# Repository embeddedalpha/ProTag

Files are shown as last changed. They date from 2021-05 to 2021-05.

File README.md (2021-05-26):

# ProTag  

### Schematic:

### 1
ProTag_Back_Ortho

### 2
ProTag_Front

### 3
ProTag_Back

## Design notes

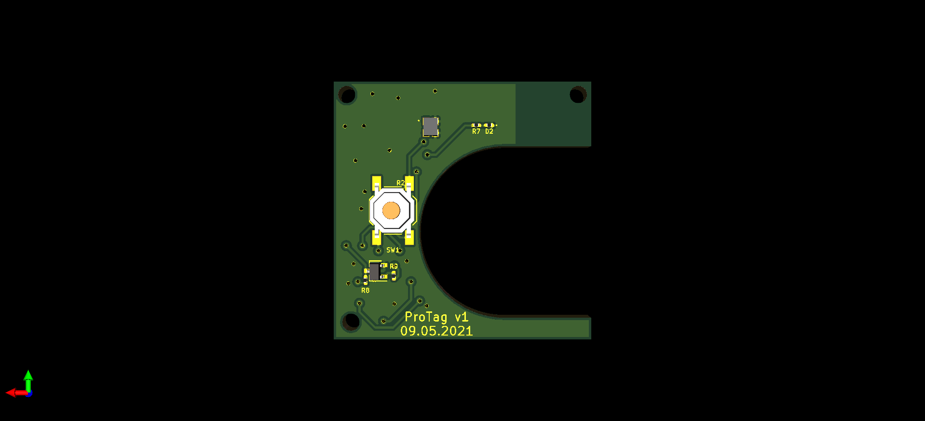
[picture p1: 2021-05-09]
Photos/ProTag_Back.png

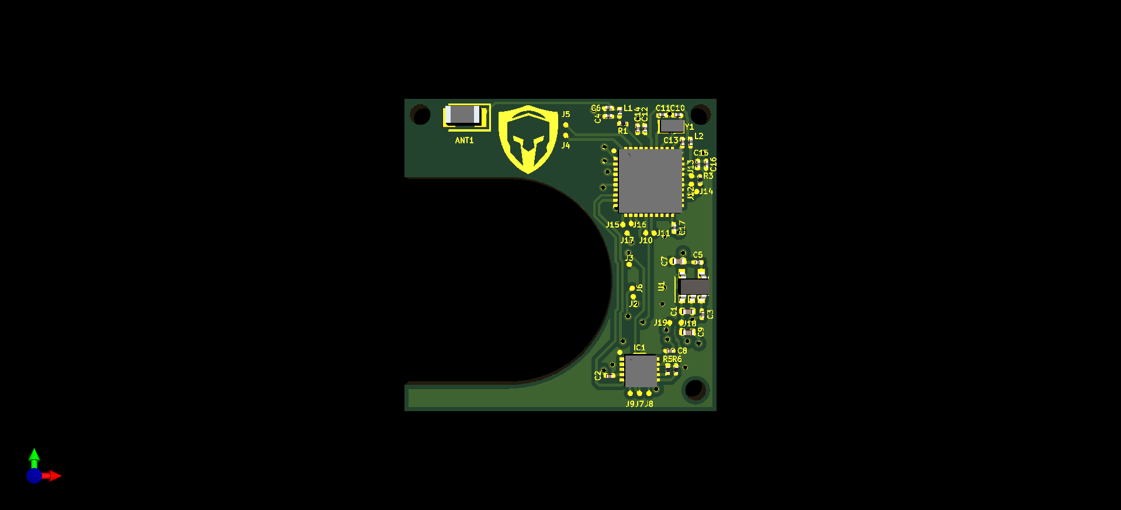
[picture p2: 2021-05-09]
Photos/ProTag_Front.png

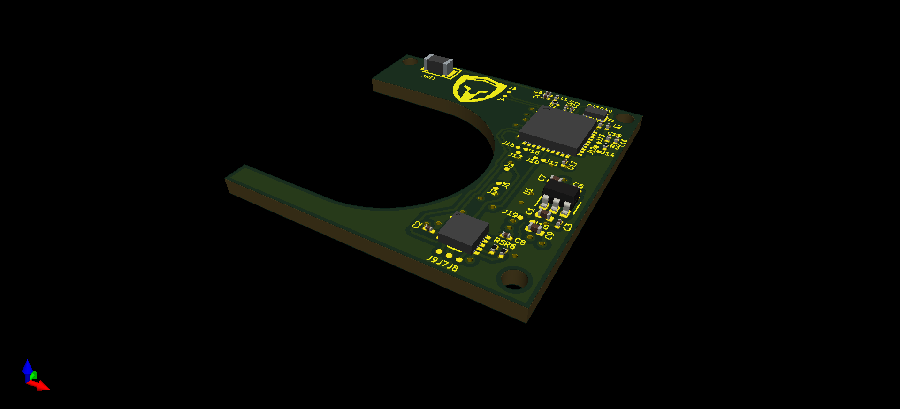
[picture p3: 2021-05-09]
Photos/ProTag_Back_Ortho.png

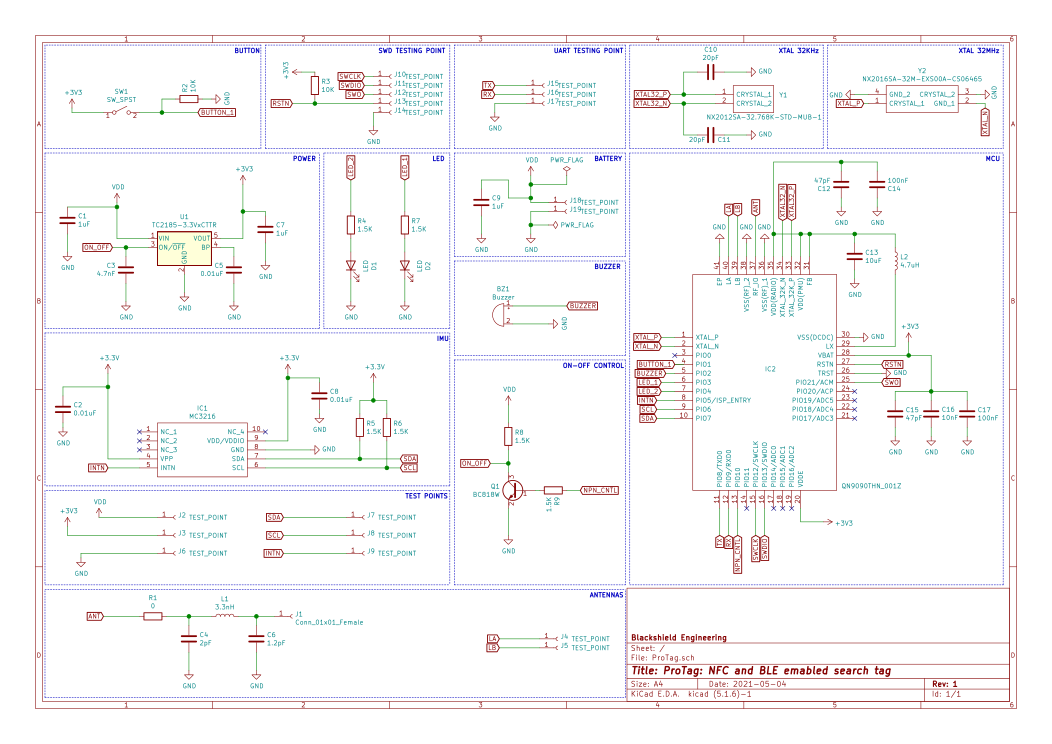
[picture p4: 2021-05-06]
Photos/ProTag.png

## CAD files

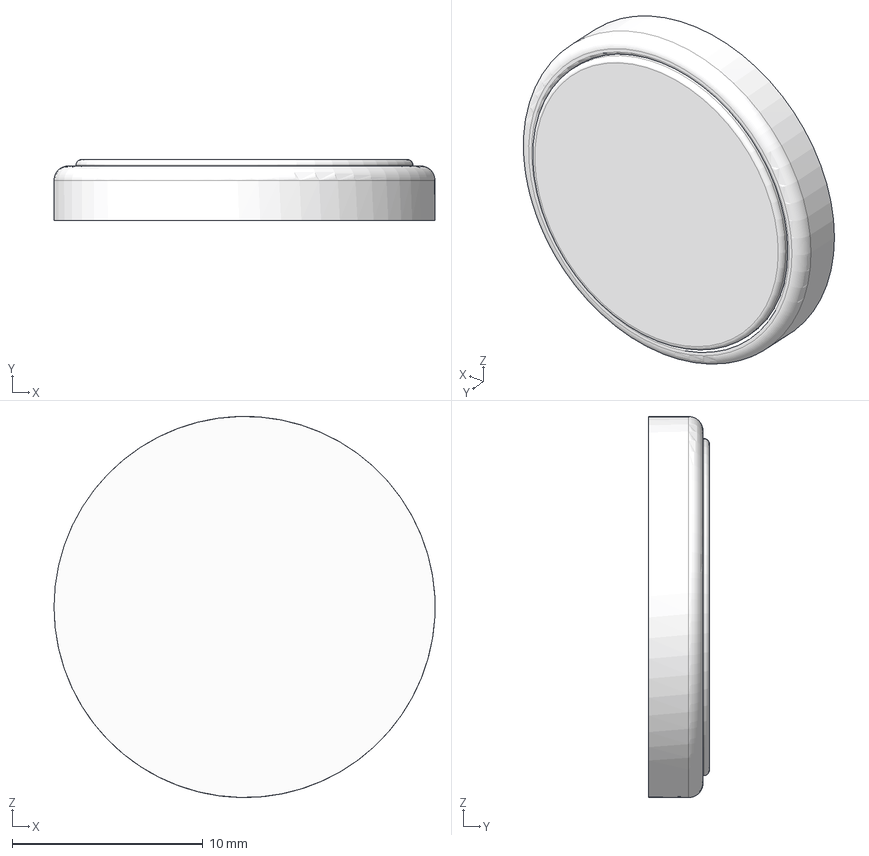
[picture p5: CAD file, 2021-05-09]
Hardware/3D/CR-2032 v1.step
20.0 x 3.20 x 20.0 mm

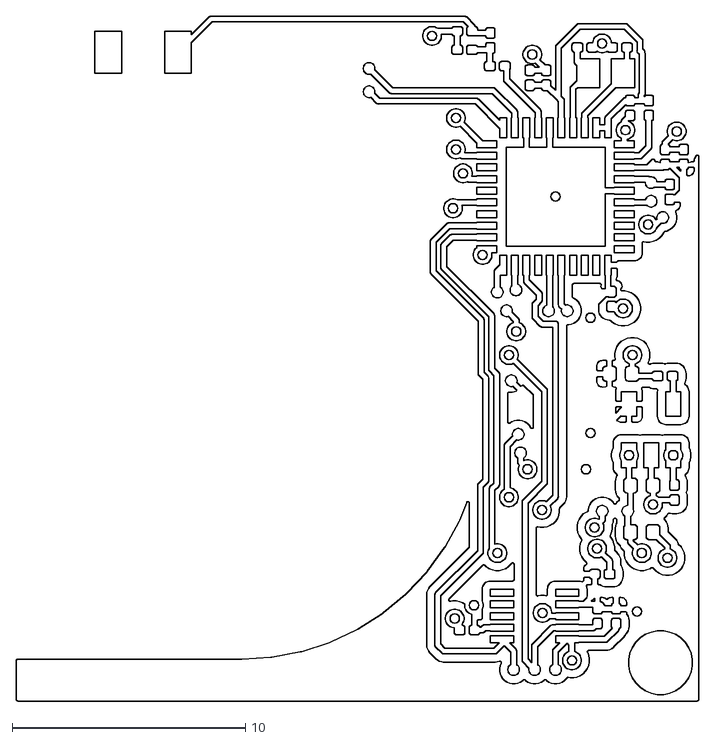
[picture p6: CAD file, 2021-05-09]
Hardware/DXF/ProTag-F_Cu.dxf
29.3 x 29.4

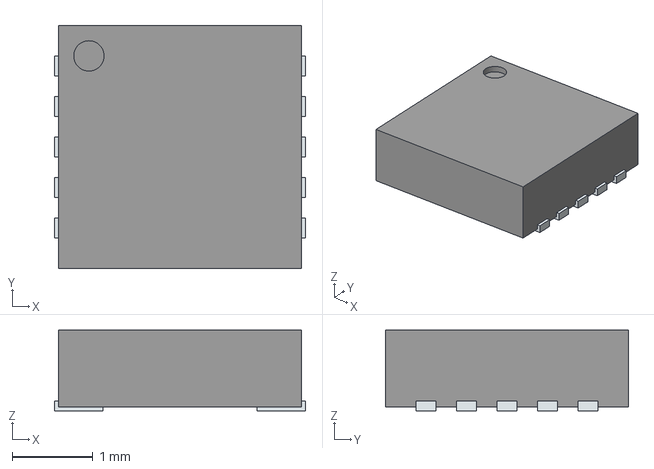
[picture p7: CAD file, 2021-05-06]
Hardware/3D/MC3216.stp
3.10 x 3.00 x 1.00 mm
PinsArrayLR

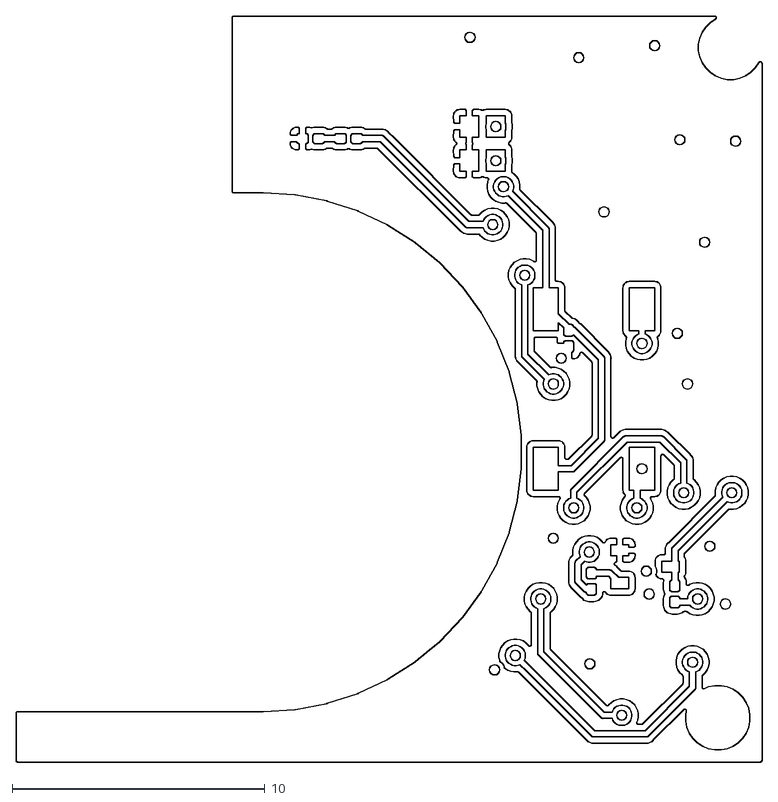
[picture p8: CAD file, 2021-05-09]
Hardware/DXF/ProTag-B_Cu.dxf
29.5 x 29.5

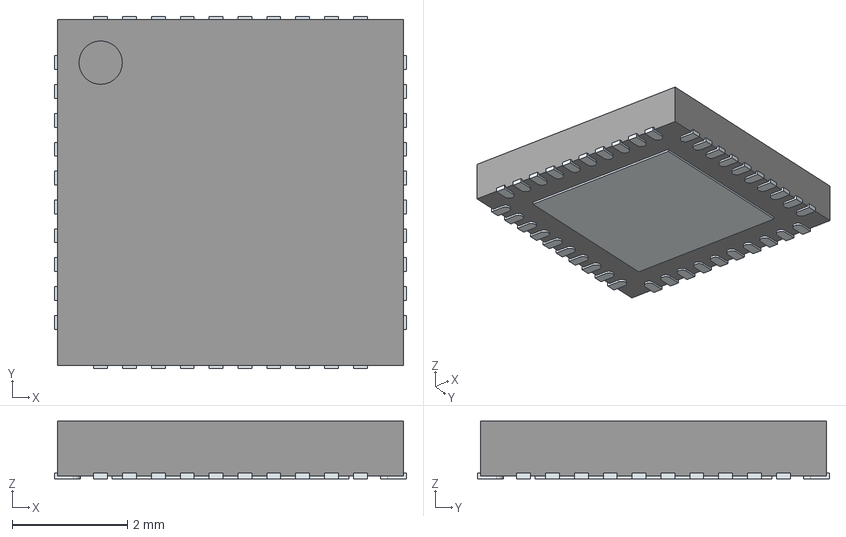
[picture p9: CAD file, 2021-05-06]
Hardware/3D/QN9090THN_001Z.stp
6.10 x 6.10 x 1.00 mm
ThermalPin
PinsArrayLR
PinsArrayTB

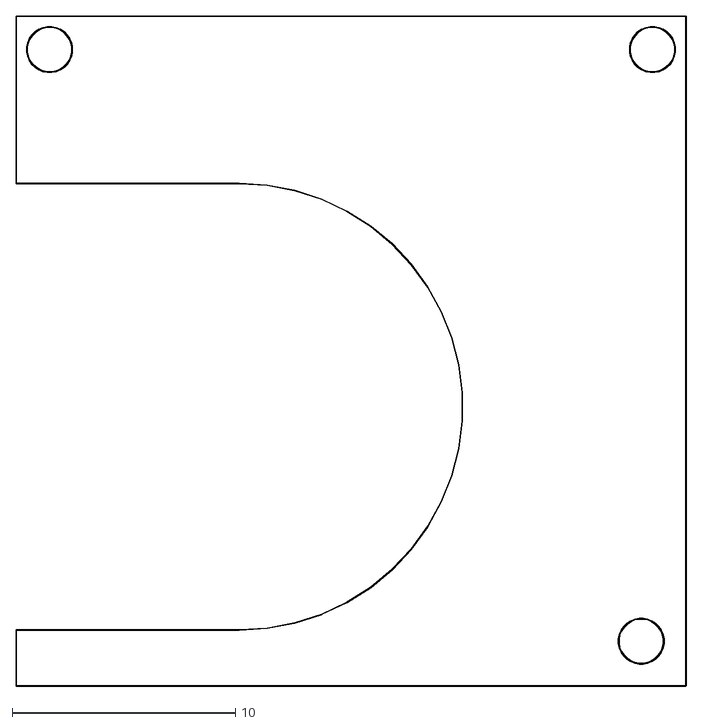
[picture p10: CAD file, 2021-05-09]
Hardware/DXF/ProTag-Edge_Cuts.dxf
30.0 x 30.0

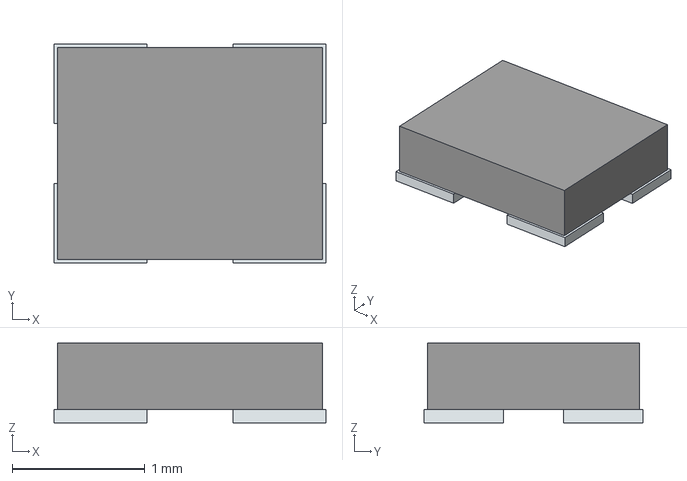
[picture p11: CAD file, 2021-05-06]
Hardware/3D/NX2016SA-32M-EXS00A-CS06465.stp
2.05 x 1.65 x 0.6 mm
Pins

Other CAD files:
Hardware/DXF/ProTag-B_Mask.dxf
Hardware/DXF/ProTag-B_Paste.dxf
Hardware/DXF/ProTag-B_SilkS.dxf
Hardware/DXF/ProTag-F_Mask.dxf
Hardware/DXF/ProTag-F_Paste.dxf
Hardware/DXF/ProTag-F_SilkS.dxf

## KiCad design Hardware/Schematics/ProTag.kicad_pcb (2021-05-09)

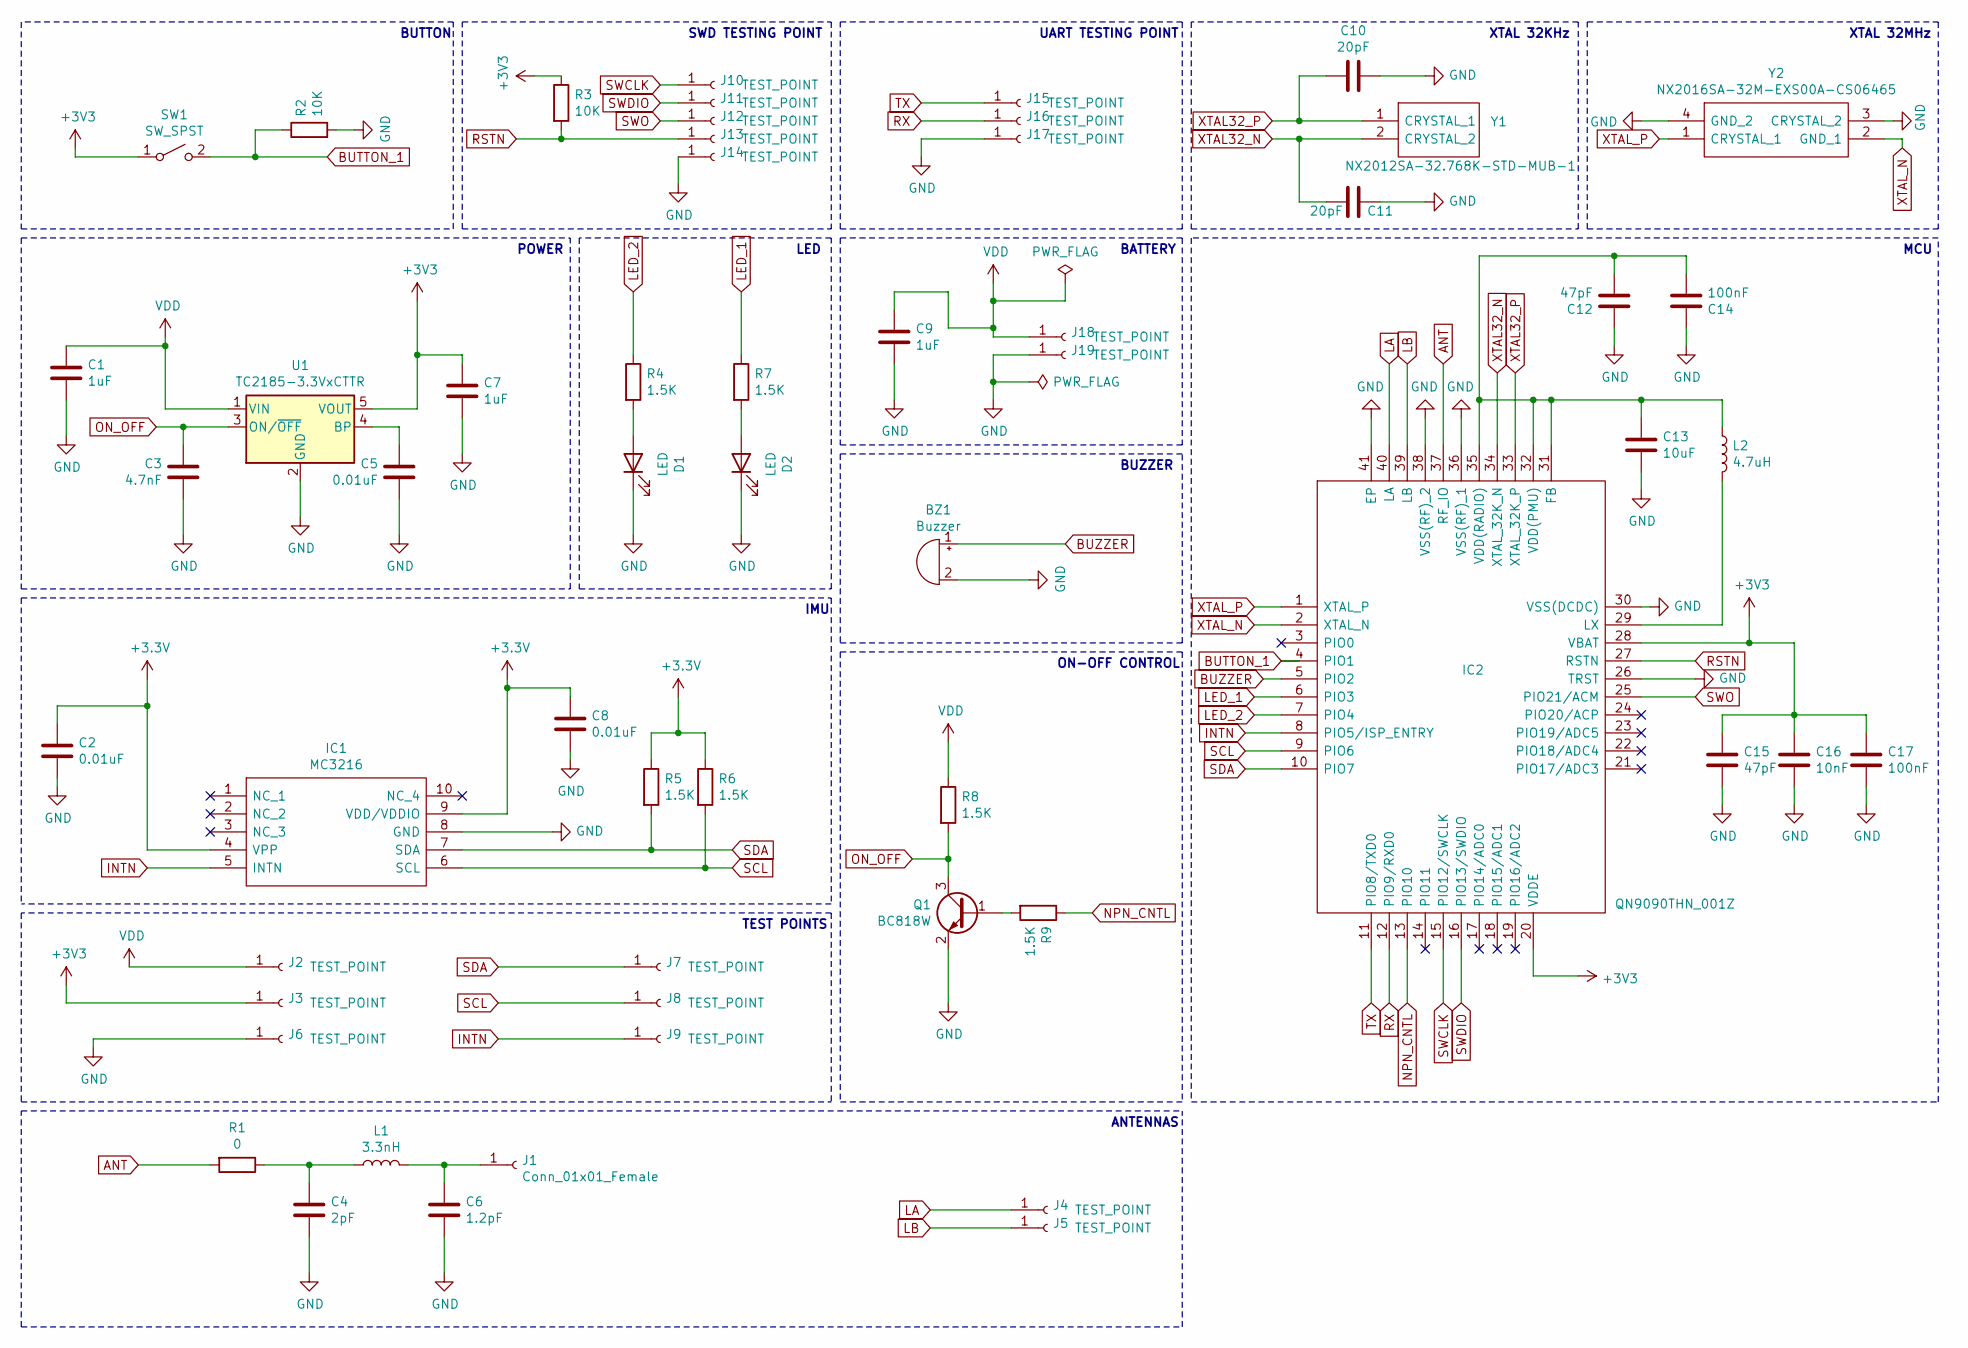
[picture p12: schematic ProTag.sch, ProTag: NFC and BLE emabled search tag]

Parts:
BZ1: Buzzer
C1, C7, C9: 1uF; C_0402_1005Metric
C2, C5, C8: 0.01uF; C_0201_0603Metric
C3: 4.7nF; C_0201_0603Metric
C4: 2pF; C_0201_0603Metric
C6: 1.2pF; C_0201_0603Metric
C10, C11: 20pF; C_0201_0603Metric
C12, C15: 47pF; C_0201_0603Metric
C13: 10uF; C_0201_0603Metric
C14, C17: 100nF; C_0201_0603Metric
C16: 10nF; C_0201_0603Metric
D1, D2: LED; D_0201_0603Metric
IC1: MC3216; SON50P300X300X100-10N; Mouser Part Number 498-MC3216
IC2: QN9090THN_001Z; QFN50P600X600X100-41N-D; Mouser Part Number 771-QN9090THN/001Z
J1: Conn_01x01_Female; TestPoint_Pad_D1.0mm
J2, J3, J4, J5, J6, J7, J8, J9, J10, J11, J12, J13, J14, J15, J16, J17, J18, J19: TEST_POINT; TestPoint_Pad_D1.0mm
L1: 3.3nH; L_0201_0603Metric
L2: 4.7uH; L_0201_0603Metric
Q1: BC818W; SOT-323_SC-70
R1: 0; R_0201_0603Metric
R2, R3: 10K; R_0201_0603Metric
R4, R5, R6, R7, R8, R9: 1.5K; R_0201_0603Metric
SW1: SW_SPST; SW_SPST_TL3342
U1: TC2185-3.3VxCTTR; SOT-23-5
Y1: NX2012SA-32.768K-STD-MUB-1; NX2012SA32768KSTDMUB1; Mouser Part Number 344-NX2012SA32768K1
Y2: NX2016SA-32M-EXS00A-CS06465; NX2016SA32MEXS00ACS06465; Mouser Part Number 344-NX2016SA32S06465

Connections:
ANT: IC2.37 (RF_IO), R1.2
BUTTON_1: IC2.4 (PIO1), R2.1, SW1.2 (B)
BUZZER: BZ1.1 (-), IC2.5 (PIO2)
GND: BZ1.2 (+), C1.1, C2.1, C3.1, C4.2, C5.1, C6.2, C7.1, C8.1, C9.1, C10.1, C11.2, C12.2, C13.2, C14.2, C15.2, C16.1, C17.2, D1.1 (K), D2.1 (K), IC1.8 (GND), IC2.26 (TRST), IC2.30 (VSS(DCDC)), IC2.36 (VSS(RF)_1), IC2.38 (VSS(RF)_2), IC2.41 (EP), J6.1, J14.1, J17.1, J19.1, Q1.2 (E), R2.2, U1.2 (GND), Y2.3 (CRYSTAL_2), Y2.4 (GND_2)
INTN: IC1.5 (INTN), IC2.8 (PIO5/ISP_ENTRY), J9.1
LA: IC2.40 (LA), J4.1
LB: IC2.39 (LB), J5.1
LED_1: IC2.6 (PIO3), R7.1
NPN_CNTL: IC2.13 (PIO10), R9.1
unnamed 9: C6.1, J1.1, L1.2; also elsewhere on the board
unnamed: C4.1, L1.1, R1.1
unnamed: C5.2, U1.4 (BP)
unnamed: C12.1, C13.1, C14.1, IC2.31 (FB), IC2.32 (VDD(PMU)), IC2.35 (VDD(RADIO)), L2.1
unnamed: D1.2 (A), R4.2
unnamed: D2.2 (A), R7.2
unnamed: IC2.7 (PIO4), R4.1
unnamed: IC2.29 (LX), L2.2
unnamed: Q1.1 (B), R9.2
ON_OFF: C3.2, Q1.3 (C), R8.2, U1.3 (ON/~OFF~)
RSTN: IC2.27 (RSTN), J13.1, R3.2
RX: IC2.12 (PIO9/RXD0), J16.1
SCL: IC1.6 (SCL), IC2.9 (PIO6), J8.1, R6.2
SDA: IC1.7 (SDA), IC2.10 (PIO7), J7.1, R5.2
SWCLK: IC2.15 (PIO12/SWCLK), J10.1
SWDIO: IC2.16 (PIO13/SWDIO), J11.1
SWO: IC2.25 (PIO21/ACM), J12.1
TX: IC2.11 (PIO8/TXD0), J15.1
VDD: C1.2, C9.2, J2.1, J18.1, R8.1, U1.1 (VIN)
XTAL32_N: C11.1, IC2.34 (XTAL_32K_N), Y1.2 (CRYSTAL_2)
XTAL32_P: C10.2, IC2.33 (XTAL_32K_P), Y1.1 (CRYSTAL_1)
XTAL_N: IC2.2 (XTAL_N), Y2.2 (GND_1)
XTAL_P: IC2.1 (XTAL_P), Y2.1 (CRYSTAL_1)

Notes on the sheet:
MCU
XTAL 32MHz
XTAL 32KHz
UART TESTING POINT
SWD TESTING POINT
BUTTON
ANTENNAS
POWER
BATTERY
LED
IMU
BUZZER
TEST POINTS
ON-OFF CONTROL

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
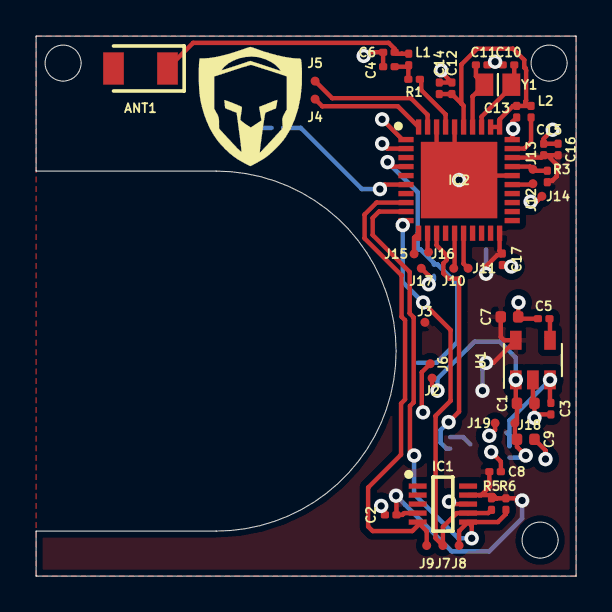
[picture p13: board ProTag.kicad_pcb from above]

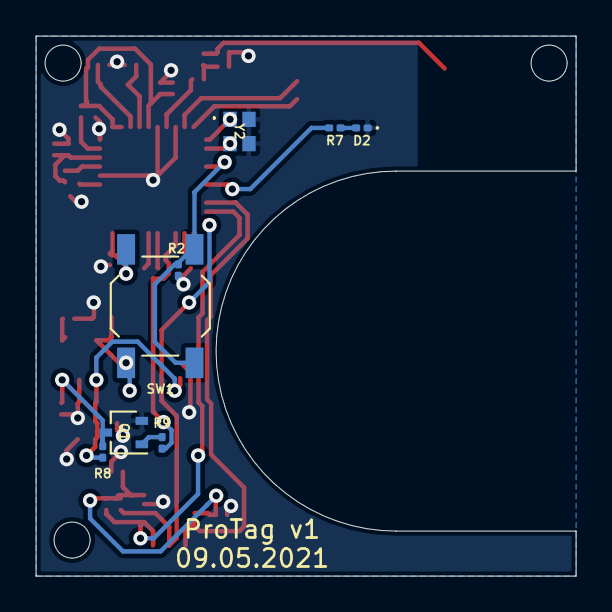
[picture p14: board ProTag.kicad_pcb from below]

Board: 2 copper layers, 30.0 x 30.0 mm, 54 parts (8 on the bottom side), 30 nets.

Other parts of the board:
ANT1: 2450AT18B100E; ANTC3216X140N

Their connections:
unnamed 9: ANT1.1; also elsewhere on the board
